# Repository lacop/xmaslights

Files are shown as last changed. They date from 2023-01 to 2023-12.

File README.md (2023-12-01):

# Xmas Lights

Notes for my xmas lights setup. Unlikely to be useful to anyone else, but why not publish it?

Each year is in its own subdirectory. (Some stuff is just copied and yes I could use git tags or something but this is more convenient and this isn't a project where I expect collaboration or maintenance).

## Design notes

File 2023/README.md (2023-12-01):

# 2023 Setup

Archived setup used for the December 2023 season.

Check out the individual section READMEs:

| Section | Description |
| --- | --- |
| [models](models/README.md) | 3D models for 3D printing |
| [mounting](mounting/README.md) | Mounting the lights on the fence |
| [wiring](wiring/README.md) | Wiring the electronics box |
| [pico](pico/README.md) | Raspberry Pi Pico light controller firmware |
| [rpi](rpi/README.md) | Raspberry Pi lights driver software |

## Ideas for improvement

- Get custom PCB made for the electronics box.
  - Include sockets for the Pico and the RPi (or other controllers).
  - Plug-in terminal blocks for the power and data lines.
- Better control software.
  - Pico could run two cores, one for serial->lights, one for the rest (watchdog, DHT readings etc).
  - More user-friendly interface for controlling the lights eg. web interface.
  - Better monitoring (graphana or MQTT).

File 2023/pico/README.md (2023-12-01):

# Firmware for the RP2040 controller

Using Waveshare RP2040-LCD-0.96 board, but any RP2040 board should work.

`boot.py` sets up USB CDC channel for sending over the color data. `code.py` just listens on the serial port and updates the lights, sending back DHT22 readings and error messages. FPS is also `print()`-ed to the stdout which shows up on the LCD.

The single buffer pixel is used as an indicator light, should alternate colors on every successfully received frame.

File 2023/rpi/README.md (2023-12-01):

# Lights control software

`lights.py` is the entrypoint which talks to the Pico over serial and handles systemd watchdog, light offsets, DHT22 readings etc.

`show.py` has the animations and schedule.

This is very basic but it works. More animations can be easily added and `scp`-ed over to the RPi.

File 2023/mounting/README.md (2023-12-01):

# Mounting

Three strings of 100 leds, ~10m each. Mounted on three fence sections, each with 80 leds, roughly centered on the string. The ~10 extra leds / ~1m of cable extra on each side is used to connect strings together and add power injection.

Attached to fence via 3d printed cable clips: See [models](../models/README.md). Need 11 clips per fence, 5 on top, 6 on the bottom. Place the clips like in the diagram, then use zipties to secure the lights, with 10 leds between every two clips.

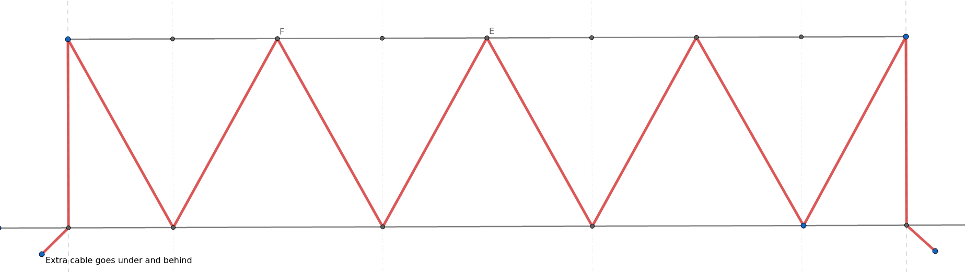
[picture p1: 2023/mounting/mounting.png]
Fence diagram


One cable has the connector installed backwards, use <https://www.printables.com/model/322266-cable-wrap-for-waterpoof-3pin-ws2811-light-cable> to make it water-tight.

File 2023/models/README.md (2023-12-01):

# Models for 3D printing

## Electronics box organization

Three separate pieces for ease of printing and flexibility of replacement. Print one of each.

* Base plate to which everything attaches.
* Mounting plate for a breadboard.
* Mounting plate for a Raspberry Pi.

Secure the Meanwell LRS-150-12 PSU to the base plate with three M3 screws. Add two M3 heatset-inserts to each mounting plate and secure it to the base plate with two M3 screws. Also use four M2 screws and heatset-inserts to secure the RPi to its mounting plate.

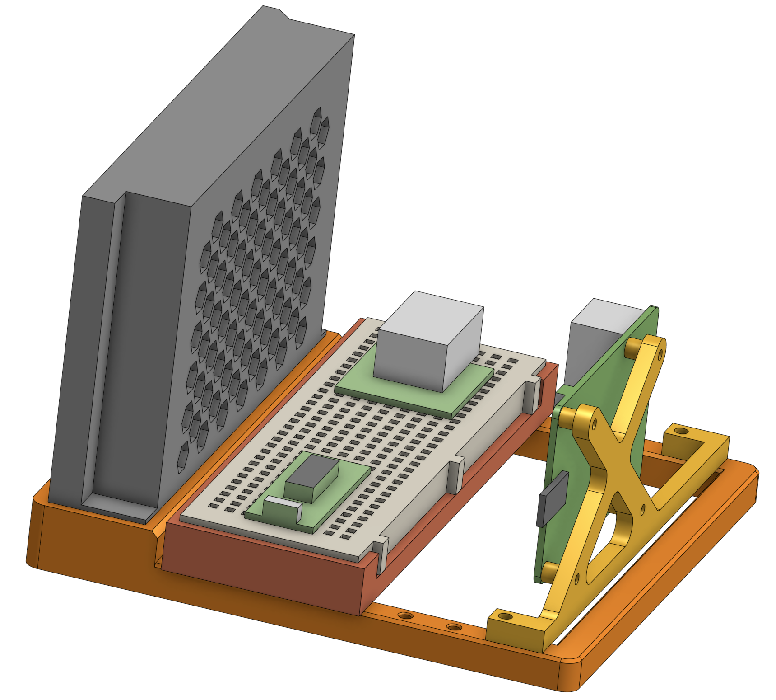
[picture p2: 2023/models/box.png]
Box organization models

*(Base plate and mounting plates in shades of red/yellow/orange. PSU, breadboard, RPi, RPi Pico and DHT22 are off the shelf parts.)*

## Fence clip

Snap-in fence clips with zip-tie channel to secure the light string. Print 3x11 = 33 pieces + extras for breakage during install.

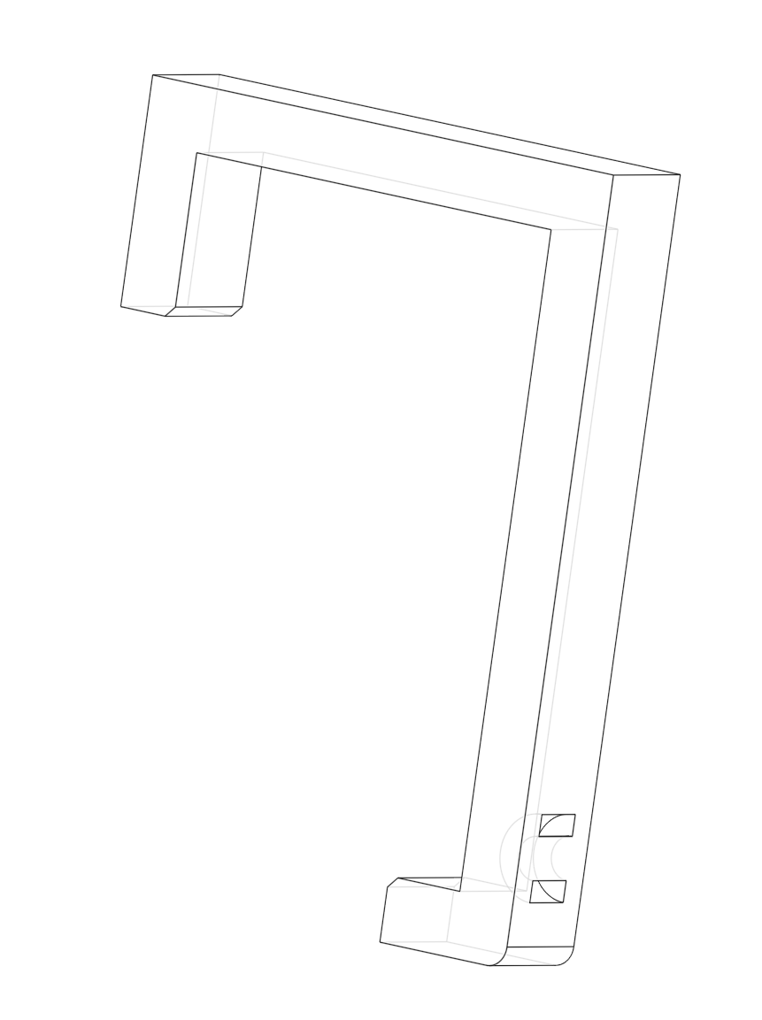
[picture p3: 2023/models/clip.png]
Fence clip render


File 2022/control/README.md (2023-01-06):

# Control software

This is just a very hacky python script with few hardcoded animations.

Run it on some proxmox VM or something (runscript to start on restart). Will switch between animations, warmup (few white leds to keep PSU active and heating up the enclosure) and off. Pushes metrics (temperature/humidity, mode etc) to MQTT.

The LED offsets are hardcoded, assuming 3 fence sections with 80 LEDs each. Might need adjusting depending on how the mounting goes.

Tons of room for improvement, the animations could be fancier. Could also integrate with ledfx (as listener to recalculate offsets and forward the packet, keeping the metrics) to have music sync etc.

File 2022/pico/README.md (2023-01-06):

# CircuitPython code for Raspberry Pico W

Code running on the RPi Pico W, listening for packets and driving the RGB LED strings.

Runs a basic loop listening for UDP packets with simple custom protocol. Displays the provided RGB values. Occasionally reads temperature/humidity data from DHT22 sensor and occasionally responds to the UDP sender with basic statistics.

# Notes and caveats:

Assumes there is one more pixel at the front of the chain which is used as status light. This is originally added to help with signal integrity (see the wiring readme) but is convenient for debugging too.

The DHT readings are not reliable, sometimes they seem to break after few days. My theory is that the 1wire timing via pulseio breaks when internal clock timer gets too big (float precision issues) though checking the code it seems integer timers are used. Who knows, maybe the sensor itself is crap.

The whole thing sometimes glitched and stopped responding. Unclear why, but adding watchdog might help. Unplugging and plugging it back in resolved the issue.

## Setup instructions:

- Setup CircuitPython on the Pico W.
- Copy `secrets.py.sample` to `secrets.py` and edit it.
- Edit `config.py` as necessary (pin numbers)
- Copy all the code from this directory to the pico.
- Verify via the REPL that this works.
- Copy `lights.py` as `code.py` to have it auto-start.

## Credits

CRC8 library is from https://pypi.org/project/crc8/

DHT library is based on https://github.com/adafruit/Adafruit_CircuitPython_DHT

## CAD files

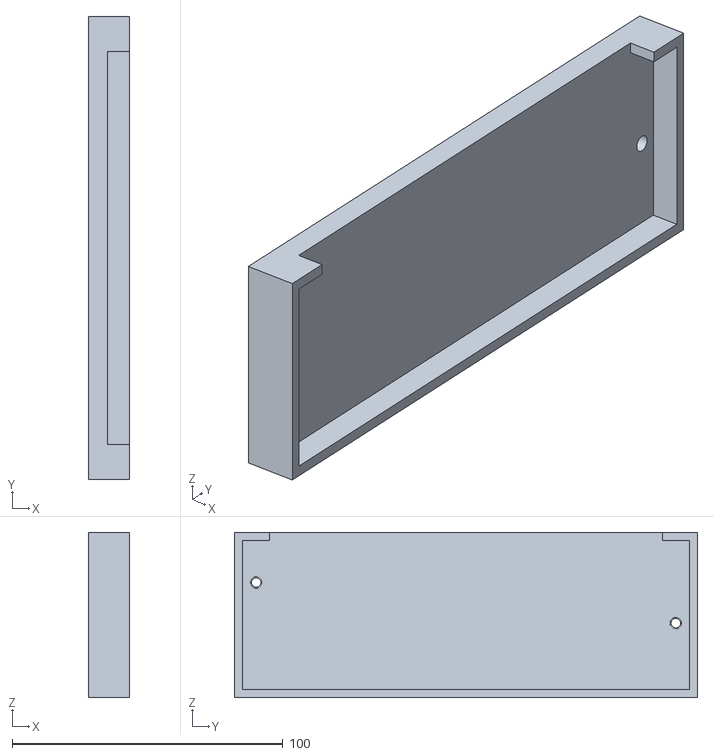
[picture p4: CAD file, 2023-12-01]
2023/models/Breadboard holder.stl
15.0 x 171.0 x 61.0

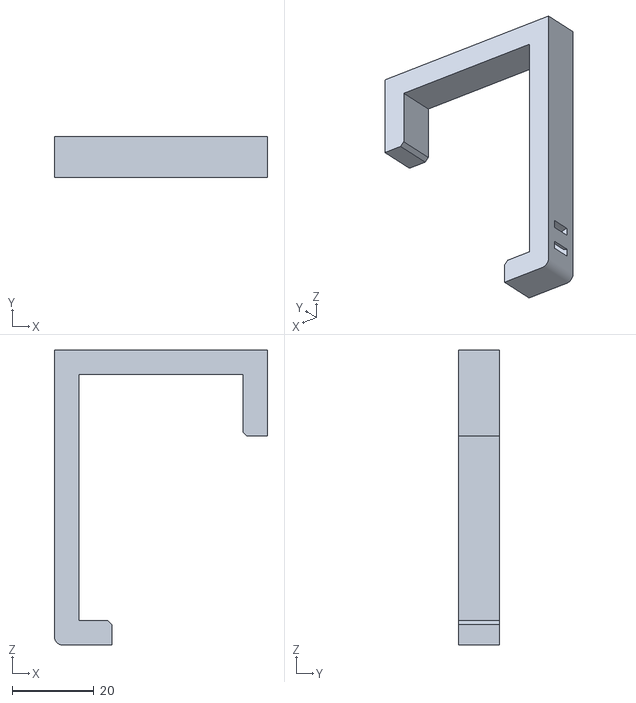
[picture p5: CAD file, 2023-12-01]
2023/models/Fence clip.stl
52.0 x 10.0 x 72.0

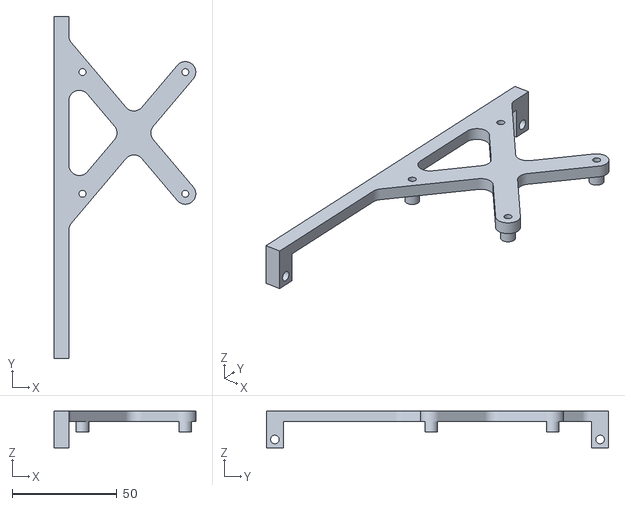
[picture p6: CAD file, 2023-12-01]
2023/models/RPi holder.stl
67.5 x 163.0 x 17.5

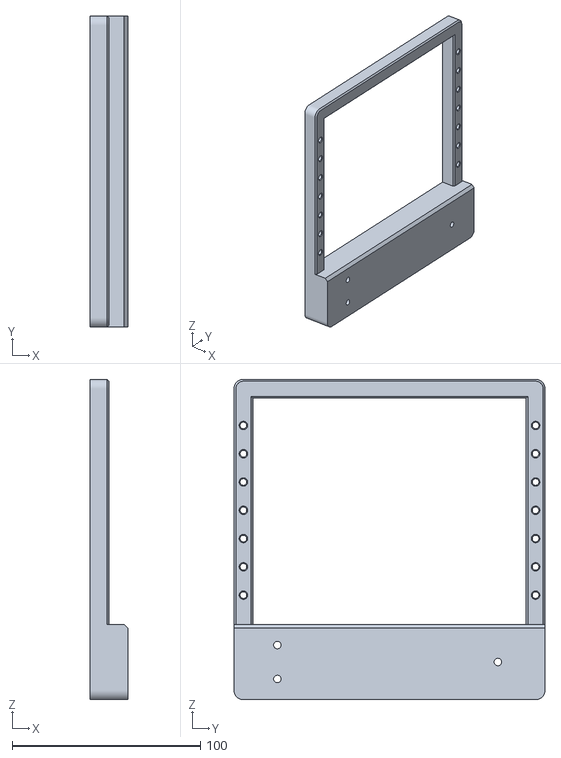
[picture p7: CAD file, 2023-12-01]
2023/models/Base plate.stl
20.0 x 165.0 x 170.0

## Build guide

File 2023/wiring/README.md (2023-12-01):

# Wiring

Everything is inside large tupperware container with cable glands. Throw in a few sillica gel bags for good measure.

Has to be well insulated - double-stacked polystyrene sheets all around and on top, with an extra thick piece at the bottom. Make sure there is very little empty space inside to prevent airflow. Cover the whole thing with plastic sheet to deflect rain and wind.

(TODO more pictures from outside install)

External cables:

- Power cord (240V).
- Power+Data for lights.
- 2x extra power injection for lights.

Internal components:

- Meanwell LRS-150-12: 12V 150W PSU.
- Breadboard with RPi Pico (well, waveshare RP2040-LCD-0.96 actually, but those are compatible) and DHT22 sensor.
- Raspberry Pi 4B, connected to the RP2040 via USB for power and data.
- Power plug + USB power supply for the RPi 4B.
- Bunch of Wago connectors to join things together.

Internal wiring:

- Power:
  - External power cord -> Live/Neutral/Earth to the PSU input
  - Power plug -> also Live/Neutral/Earth of the PSU
  - 12V output of PSU -> Wago -> power lines of the light cables (3x)
  - USB charger in power plug -> USB cable to RPi 4B
  - Ground pin of RP2040 -> negative output of PSU (via Wago) to tie grounds toger
- Signal
  - RP2040 -> DHT signal
  - Light drive pin -> Offcut WS281x pixel -> Output data cable

The offcut single pixel serves as logic convertor (RP2040 3v3 -> 5v) and signal conditioning. Tried to use level shifter before but it was glitching.

(TODO wiring diagram)

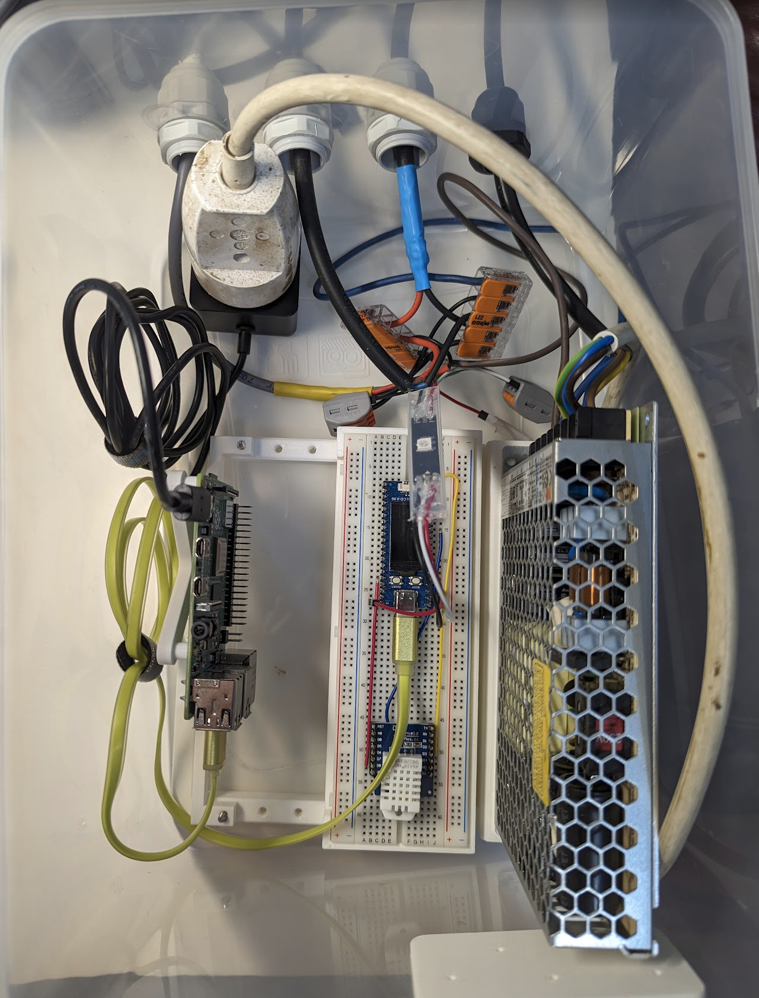
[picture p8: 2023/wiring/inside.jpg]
Inide of the box


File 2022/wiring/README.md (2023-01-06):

# Wiring

Everything is inside large tupperware container with cable glands. Throw in a few sillica gel bags for good measure.

Has to be well insulated - double-stacked polystyrene sheets all around and on top, with an extra thick piece at the bottom. Make sure there is very little empty space inside to prevent airflow. Cover the whole thing with plastic sheet to deflect rain and wind.

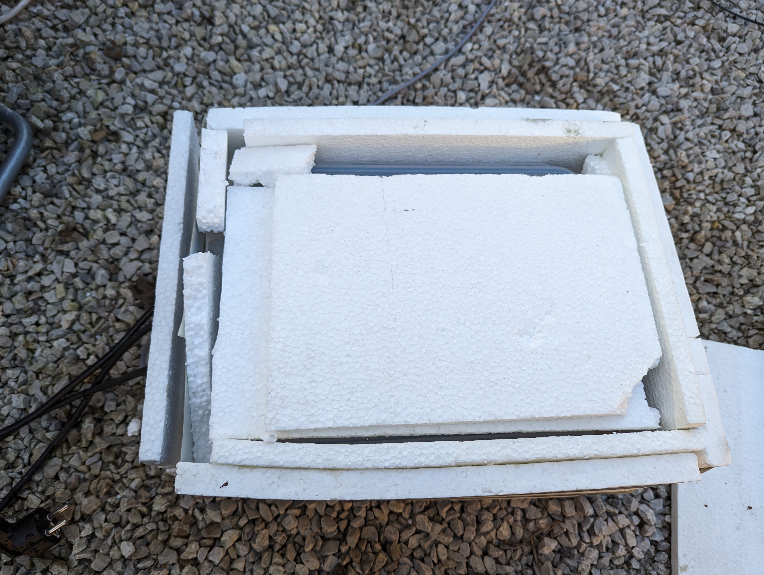
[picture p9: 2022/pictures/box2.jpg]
Box2
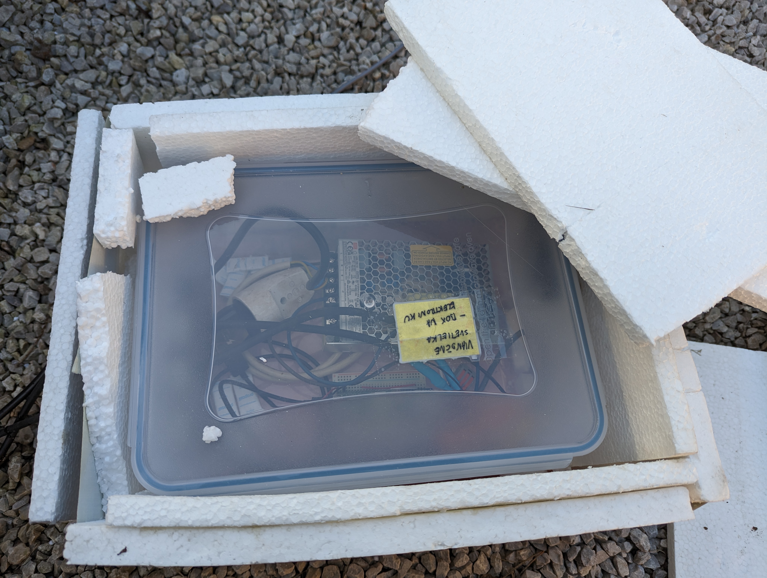
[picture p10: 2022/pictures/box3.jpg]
Box3
| Box1 |  |  |
| --- | --- | --- |

External cables:

- Power cord (240V)
- Power+Data for lights
- 2x extra power injection for lights

Internal components:

- Meanwell LRS-150-12: 12V 150W PSU
- Power plug for 5V USB power supply (for Pico)
- Breadboard with RPi Pico W and DHT22 sensor
- Bunch of Wago connectors to join things together

Internal wiring:

- Power:
  - External power cord -> Live/Neutral/Earth to the PSU input
  - Power plug -> also Live/Neutral/Earth of the PSU
  - 12V output of PSU -> Wago -> power lines of the light cables (3x)
  - USB charger in power plug -> USB cable to Pico
  - Ground pin of Pico -> negative output of PSU (via Wago) to tie grounds toger
- Signal
  - Pico -> DHT signal
  - Light drive pin -> Offcut WS281x pixel -> Output data cable

The offcut single pixel serves as logic convertor (pico 3v3 -> 5v) and signal conditioning. Tried to use level shifter before but it was glitching.

Diagram

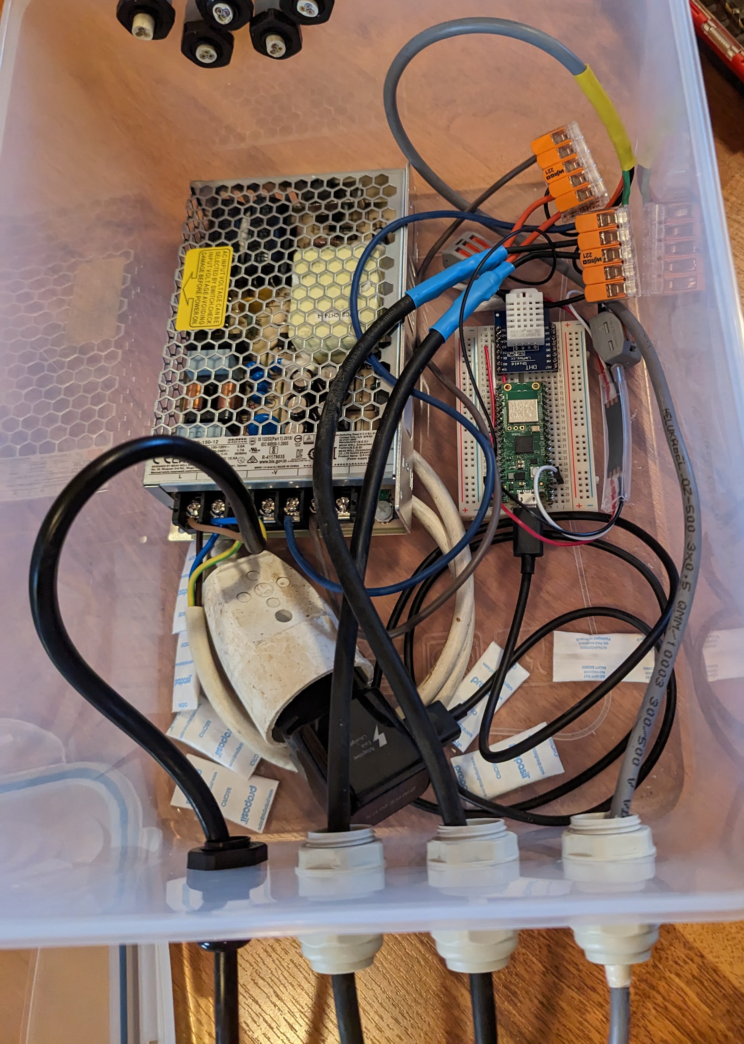
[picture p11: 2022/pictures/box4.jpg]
Box4


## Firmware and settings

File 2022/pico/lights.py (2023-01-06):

import board
from crc8 import crc8
import errno
import fastdht
import microcontroller
import neopixel
import socketpool
import struct
import time
import wifi

try:
    import config
    import secrets
except ImportError:
    print('Failed to open config.py or secrets.py')
    raise

print('STARTING')

print('Clearing out all LEDS, count:', config.LED_COUNT)
# +1 pixel always for the one acting as buffer / level shifter / status indicator
pixels = neopixel.NeoPixel(config.LED_PIN, config.LED_COUNT + 1, auto_write=False)
for i in range(config.LED_COUNT + 1):
    pixels[i] = 0
pixels.show()

print('Setting up...')
pixels[0] = (255, 165, 0)
pixels.show()

print('My mac:', ':'.join('{:02x}'.format(b) for b in wifi.radio.mac_address))
print('Attempting to connect to:', secrets.WIFI_SSID)

wifi.radio.connect(secrets.WIFI_SSID, secrets.WIFI_PASSWD)

print('Connected!')
print('My IP:', wifi.radio.ipv4_address)

pool = socketpool.SocketPool(wifi.radio)
sck = pool.socket(socketpool.SocketPool.AF_INET, socketpool.SocketPool.SOCK_DGRAM)
sck.bind((str(wifi.radio.ipv4_address), config.UDP_PORT))
sck.settimeout(5)
print('UDP listening on port', config.UDP_PORT)

# print('Setting up DHT')
# dht = adafruit_dht.DHT22(config.DHT_PIN)
# dht.measure()
dht = fastdht.FastDHT(config.DHT_PIN)

print('Entering listen loop...')
pixels[0] = (60, 0, 100)
pixels.show()

# Buffer size:
# - 4 byte magic 'LGHT'
# - 2 bytes for order
# - 2 bytes for length (entire packet)
# - 3x bytes for RGB values
# - 1 byte CRC8
MAX_PACKET_LEN = 4 + 2 + 2 + 3*config.LED_COUNT + 1
buffer = bytearray(MAX_PACKET_LEN + 16) # 16 = extra buffer

STATUS_COLORS = {
    # OK, receiving packets. Green variants.
    'ok': [(25, 75, 25), (5, 30, 5)],
    # Socket read timeout. Yellow variants.
    'timedout': [(50, 30, 10), (40, 20, 15)],
    # Socket read timeout and ping failed. Red variants.
    'timedoutfailedping': [(150, 20, 0), (150, 0, 20)],
    # Bad packets. Redish variants.
    'badpacket': [(95, 20, 10), (80, 10, 20)],
}
last_status_color = 0
def set_status_color(status):
    global last_status_color
    pixels[0] = STATUS_COLORS[status][last_status_color % len(STATUS_COLORS[status])]
    last_status_color += 1

# Last good packet.
last_received_order = 0
last_good_ns = 0

# Statistics.
stats_sent_ns = 0
# Contents:
# All values capped at 255 (avoid overflow), but should fit safely.
# All values reset when sent, except counter and dht_*.
# - 1 byte: Stats packet order, wraps around.
# - 1 byte: Times timed out.
# - 1 byte: Total packets received.
# - 1 byte: Missed packets.
# - 1 byte: Bad packets. Received - bad = displayed.
# - 1 byte: Max processing time since last report as ms.
# - 1 byte: DHT read errors count.
# - 1 byte: Seconds since last good DHT measurement.
# - 2 byte: Temperature * 10. Last good measurement.
# - 2 byte: Humidity * 10. Last good measurement.
# - 1 byte: CRC8
statsbuffer = bytearray(13)
stats_order = 0
stats_timeouts = 0
stats_packets_total = 0
stats_packets_missed = 0
stats_packets_bad = 0
stats_max_process_time_ns = 0

dht_read_errors = 0
dht_last_read_ns = 0
dht_last_good_read_ns = 0
dht_last_temp = 0
dht_last_humid = 0


def fill_and_reset_stats():
    global statsbuffer, stats_order, stats_timeouts
    global stats_packets_total, stats_packets_missed, stats_packets_bad
    global stats_max_process_time_ns
    global dht_read_errors, dht_last_good_read_ns
    global dht_last_temp, dht_last_humid
    
    # Populate packet
    statsbuffer[0] = stats_order
    statsbuffer[1] = min(255, stats_timeouts)
    statsbuffer[2] = min(255, stats_packets_total)
    statsbuffer[3] = min(255, stats_packets_missed)
    statsbuffer[4] = min(255, stats_packets_bad)
    statsbuffer[5] = min(255, stats_max_process_time_ns//1000//1000)
    statsbuffer[6] = min(255, dht_read_errors)
    statsbuffer[7] = min(255, (time.monotonic_ns()-dht_last_good_read_ns)//1000//1000//1000)
    statsbuffer[8:10] = struct.pack('<h', dht_last_temp)
    statsbuffer[10:12] = struct.pack('<H', dht_last_humid)
    
    crc = crc8()
    crc.update(statsbuffer[:12])
    statsbuffer[12] = crc.digest()[0]

    # Adjust counter
    stats_order = (stats_order + 1) % 256
    # Reset everything else
    stats_timeouts = 0
    stats_packets_total = 0
    stats_packets_missed = 0
    stats_packets_bad = 0
    stats_max_process_time_ns = 0
    dht_read_errors = 0


def badpacket():
    global last_good_ns
    set_status_color('badpacket')
    # Clear out everything else if we keep getting bad data.
    if time.monotonic_ns() - last_good_ns > 5*1000*1000*1000:
        for i in range(config.LED_COUNT):
            pixels[i+1] = 0
    pixels.show()

failed_pings = 0

# TODO start watchdog & increment in each loop (even error)
# print('STARTING WATCHDOG NOW')
# Maximum supported by RPi Pico should be 8 seconds or so
# microcontroller.watchdog.timeout = 6 

while True:
    # Maybe read DHT values if enough time passed.
    dht_read_time = time.monotonic_ns()
    if dht_read_time - dht_last_read_ns > config.DHT_INTERVAL_SEC*1000*1000*1000:
        dht_last_read_ns = dht_read_time
        m = dht.read()
        if m:
            #print('DHT good')
            dht_last_good_read_ns = dht_read_time
            dht_last_temp, dht_last_humid = m
        else:
            dht_read_errors += 1
            #print('DHT bad')

    # Wait for network packet, with timeout.
    try:
        size, sender = sck.recvfrom_into(buffer)
    except OSError as error:
        if error.errno == errno.ETIMEDOUT:
            stats_timeouts += 1
            
            pingok = wifi.radio.ping(config.PING_IP) is not None
            if pingok:
                set_status_color('timedout')
                failed_pings = 0
            else:
                set_status_color('timedoutfailedping')
                failed_pings += 1
                print('PING FAILED, now at ', failed_pings)
                if failed_pings > 5:
                    print('!!!REBOOT!!!')
                    microcontroller.reset()

            # Clear to avoid getting stuck in display mode when network or sender is down.
            for i in range(config.LED_COUNT):
                pixels[i+1] = 0
            pixels.show()
            continue
        else:
            raise error
    stats_packets_total += 1
    failed_pings = 0
    
    # Verify the packet
    process_start = time.monotonic_ns()
    #print('Got', size, 'from', sender)
    
    if size > MAX_PACKET_LEN or size < 9 or buffer[:4] != b'LGHT':
        #print('BAD PACKET')
        badpacket()
        stats_packets_bad += 1
        continue
    
    order = struct.unpack('>H', buffer[4:6])[0]
    length = struct.unpack('>H', buffer[6:8])[0]
    packet_crc = buffer[size - 1]
    
    packet_lights = length - 9
    if length != size or packet_lights % 3 != 0:
        #print('BAD SIZE')
        badpacket()
        stats_packets_bad += 1
        continue
    packet_lights = packet_lights // 3
    
    computed_crc = crc8()
    computed_crc.update(buffer[:size - 1])
    if computed_crc.digest() != bytes([packet_crc]):
        #print('BAD CRC')
        badpacket()
        continue

    # TODO need modular math here
    if last_received_order + 1 < order:
        #print('MISSED PACKETS', order-last_received_order-1)
        stats_packets_missed += 1 # TODO increment by the real amount
        # No "continue", this is fine, just display it.
        pass
    last_received_order = order
    
    verify_end = time.monotonic_ns()
    last_good_ns = verify_end

    # Write out to pixels, toggle status
    for i in range(config.LED_COUNT):
        if i < packet_lights:
            pixels[i+1] = (buffer[8 + 3*i], buffer[8 + 3*i + 1], buffer[8 + 3*i + 2])
        else:
            pixels[i+1] = 0
    set_status_color('ok')
    # TODO power estimate and brightness control?
    # maybe better done on server side but we can at least sanity check and refuse...
    #pixels.brightness = (1.0 if order%2 == 0 else 0.5)
    pixels.show()

    process_end = time.monotonic_ns()
    stats_max_process_time_ns = max(stats_max_process_time_ns, process_end-process_start)

    if process_end - stats_sent_ns > config.STATS_INTERVAL_SEC*1000*1000*1000:
        stats_sent_ns = process_end
        fill_and_reset_stats()
        sck.sendto(statsbuffer, sender)
        #print('reply', (time.monotonic_ns()-process_end)/1000/1000)

    #TODO wrap these prints in some DEBUG_ON or whatever
    #print('Verify', (verify_end-process_start)/1000/1000, 'ms')
    #print('Write', (process_end-verify_end)/1000/1000, 'ms')

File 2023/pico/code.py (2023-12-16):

import board
import neopixel
import time
import usb_cdc

import fastdht

# Configuration.
PIXEL_COUNT = 300 # Without the first buffer/status pixel
PIXEL_PIN = board.GP0

DHT_PIN = board.GP15
DHT_INTERVAL_SECS = 30

FRAME_START = b'\xFA'
FRAME_END = b'\xFB'
FRAME_ESCAPE = b'\xFC'
PACKET_SIZE = 3 * PIXEL_COUNT

# Initialize.
print('SET UP SERIAL')
assert usb_cdc.data is not None
serial = usb_cdc.data
serial.timeout = 0.1

def log(msg):
    print(msg)
    serial.write((msg + '\n').encode('ascii'))

pixels = neopixel.NeoPixel(PIXEL_PIN, PIXEL_COUNT + 1, auto_write=False)
for i in range(PIXEL_COUNT + 1):
    pixels[i] = (0, 0, 0)
pixels[0] = (32, 0, 0)
pixels.show()

dht = fastdht.FastDHT(DHT_PIN)
last_dht_time = 0

buffer = None

last_packet_time = time.monotonic_ns()
need_clear = True

stats_time = time.monotonic_ns()
stats_counter = 0

status_color = 0

last_alive_time = time.monotonic_ns()
last_alive_state = 0

print('INFO: READY FOR DATA')
while True:
    read = serial.read(serial.in_waiting)
    if len(read) > 0:
        last_packet_time = time.monotonic_ns()
        need_clear = True
        escape = False
        for b in read:
            b = bytes([b])
            if escape:
                if b not in [FRAME_START, FRAME_END, FRAME_ESCAPE]:
                    log(f'ERROR: invalid escape byte {b}')
                else:
                    buffer += b
                escape = False
            elif b == FRAME_START:
                if buffer is None:
                    buffer = bytes()
                else:
                    log(f'ERROR: invalid start byte {b}')
                    buffer = bytes()
            elif b == FRAME_END:
                if buffer is None:
                    log(f'ERROR: invalid end byte {b}')
                elif len(buffer) == PACKET_SIZE:
                    for i in range(PIXEL_COUNT):
                        pixels[i+1] = (buffer[i*3], buffer[i*3+1], buffer[i*3+2])
                    pixels[0] = [
                        (0, 32, 0),
                        (0, 0, 32),
                    ][status_color]
                    status_color = (status_color + 1) % 2
                    pixels.show()
                    stats_counter += 1
                else:
                    log('ERROR: invalid packet size {len(buffer)}')
                buffer = None
            elif b == FRAME_ESCAPE:
                escape = True
            else:
                if buffer is not None:
                    buffer += b
    now = time.monotonic_ns()
    if stats_counter >= 20:        
        elapsed = (now - stats_time) / 1000 / 1000 / 1000
        if elapsed > 0:
            # Don't log.
            print('FPS:', stats_counter / elapsed)
            last_alive_time = now
        stats_counter = 0
        stats_time = now
    if need_clear and (now - last_packet_time)//1000//1000//1000 > 5:
        for i in range(PIXEL_COUNT + 1):
            pixels[i] = (0, 0, 0)
        pixels[0] = (32, 0, 0)
        pixels.show()
        need_clear = False
    if (now - last_dht_time)//1000//1000//1000 > DHT_INTERVAL_SECS:
        reading = dht.read()
        if reading is None:
            log('DHT: error')
            # Try again later...
            last_dht_time = now
        else:
            temp, humid = reading
            log(f'DHT: temp={temp} humid={humid}')
            last_dht_time = now
    if (now - last_alive_time)//1000//1000//1000 > 60:
        last_alive_time = now
        last_alive_state = (last_alive_state + 1) % 2
        # Just for display, don't log.
        print(f'INFO: Alive', last_alive_state)
# TODO watchdog?

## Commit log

2023-12-01 basic pico->host channel
2023-12-01 basic host side driver daemon
2023-12-01 animation framework
2023-12-01 add 3d models
    [Base plate.stl, Breadboard holder.stl, Fence clip.stl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]
2023-12-01 add mounting, mostly copied from last year
2023-12-03 add always-on lights for heating
2023-12-03 move serial handling to background thread
2023-12-03 add some cpu heating
2023-12-03 mqtt skeleton and clean up printing
2023-12-16 fix dht retry logic
    [code.py]
